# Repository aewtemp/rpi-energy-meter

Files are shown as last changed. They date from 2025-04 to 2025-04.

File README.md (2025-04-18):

# ----- W.I.P -----
# Raspberry-Pi Energy Meter

This Project is a combination of custom Hardware and Software, that will allow you to monitor your unique power situation in real time.

This project is derived from and inspired by the resources located at https://github.com/David00/rpi-power-monitor and https://learn.openenergymonitor.org.

## What does it do?
This code accompanies DIY circuitry that supports monitoring of up to 3 Phases with 6 current transformers each. The individual readings are then used in calculations to provide real data on consumption and generation, including the following key metrics:
* Voltage of every pahse
* Current on up to 6 channels per phase
* Power Factor
* Harmonics inspection through a built in snapshot/plotting mechanism.

The code takes thousands of samples per second, corrects for phase errors in the measurements, calculates the instantaneous power for the tens of thousands of sampled points, and uses the instantaneous power calculations to determine real power, apparent power, and power factor. This means the project is able to monitor any type of load, including reactive, capacitive, and resisitve loads.

## Where can I get it?
The whole Project is open sourced. You can order your PCBs via the Files provided in the [PCB Folder](PCB).  
You'll also find a [README](PCB/README.md) there which will provide more useful information.

## Installation & Documentation

### Ordering
#### Components for the PCB
Please take the respective components and their needed quantities from the [CSV](PCB/Production/RPiWattMeterHatv3.csv) inside the [PCB](PCB) folder.
#### The PCB
Just send the gerber files to the PCB Manufacturer of your choice.
If you provide the components file and the locations with the gerber files, you might be able to get the PCB nearly fully assembled.

### Preparing the Pi
#### System-Setup
You'll need a raspberry pi 3B with an installed operating system on it.
This has to be a 32-bit version, because the overlay file needed for the SPI-bus configuration won't work on 64-bit operating systems.
Currently supported operating systems are Debian (>11) and Ubuntu (>20.04)

* Copy the [overlay file (system_overlay/spi0-3cs-overlay.dtbo)](sytem_overlay/spi0-3cs-overlay.dtbo) into /boot/overlays  
* reboot

#### Installing the necessary software

### Installation and Configuration
#### Installation into the Cabinet
You will need 4 additional components to get the rpi-energy-meter up and running.
1. A DIN rail mountable power supply  
I had chosen this one: [MeanWell HDR-15-5](https://meanwell-ps.com/products/hdr-15-5)
2. 3 x fuse blocks, rated for 250V  
I had chosen this one: [XCELL UK5](https://www.uxcell.com/din-rail-mount-fuse-holder-terminal-blocks-screw-type-black-uk5-pack-p-1946790.html)
3. 3 x glass fuse, rated for 250V and 250mA  
I had chosen this one: [FUSE GLASS](https://www.digikey.de/en/products/detail/bel-fuse-inc/5HT-250-R/4439452)
4. Wires  
Ideally one would use black for the 230V live wires from and to the fuse holders, blue ones for the neutrals and red/black wires for the current transformer wires.  
The cross sections of the wires is:
    1. 230V/Neutal
        1. To the fuse blocks = 1.5mm² (15 AWG)
        1. From the fuse blocks = 0.5mm² (20 AWG)
        1. From the board (Neutral) = 0.5mm² (20 AWG)
    2. Current transformers
        1. Should be 0.5mm² or less (>= 20 AWG)

Select where you want your Voltage to be taken of for measurement. You'll have to select 3 sources, one for each phase.  
Connect wires from these points up to the fuse holders. From there you'll connect wires to the PCB - right where the imprint "DANGER HIGH VOLTAGE" is located.  
With the socket located at the bottom, left is phase 1, middle two are phase 2 and the right ones are phase 3.  
The Sequence is **N-L1-N-L2-N-L3**

#### Measuring required references
This step consists of some measurements which have to be taken in the cabinet and on the PCB. On the PCB are therefore some exposed through holes where you can take measurements from.

**!! BE CAREFUL WHEN TAKING MEASUREMENTS ON LIVE COMPONENTS !!**  

The following measurements have to be done:
* Voltages DC
    * 3.3V reference -> Exposed pads right next to the MCP3008 chips  
    Write down that value, it's needed later for the config.toml
    * Bias_V -> Exposed pads right above the Transformers on the PCB  
    Should be half of the reference Voltage
* Voltage AC
    * L{1,2,3}TRANS -> Exposed pads right next to the MCP3008 chips  
    Should read something from 2.0V to 2.2V RMS

#### Configuring the Energy-Meter

### Setting up a systemd service
* copy the [example systemd service file](examples/systemd/rpi-energy-meter.service) to /etc/systemd/system  
* modify the contents of /etc/systemd/systemd/rpi-energy-meter.service corresponding to your setup  
Most often you will need to adjust paths accordingly

### Expected results
#### Debug mode
The html charts generated by debug mode should look something like this  
[Phase 1](examples/debug/Phase_1.html?raw=true)  
[Phase 2](examples/debug/Phase_2.html?raw=true)  
[Phase 3](examples/debug/Phase_3.html?raw=true)

## Contributing

## Credits

---

## If you like what I did, you are welcome to leave me some support




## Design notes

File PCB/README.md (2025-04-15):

# ----- W.I.P -----
# Raspberry-Pi Energy Meter HAT
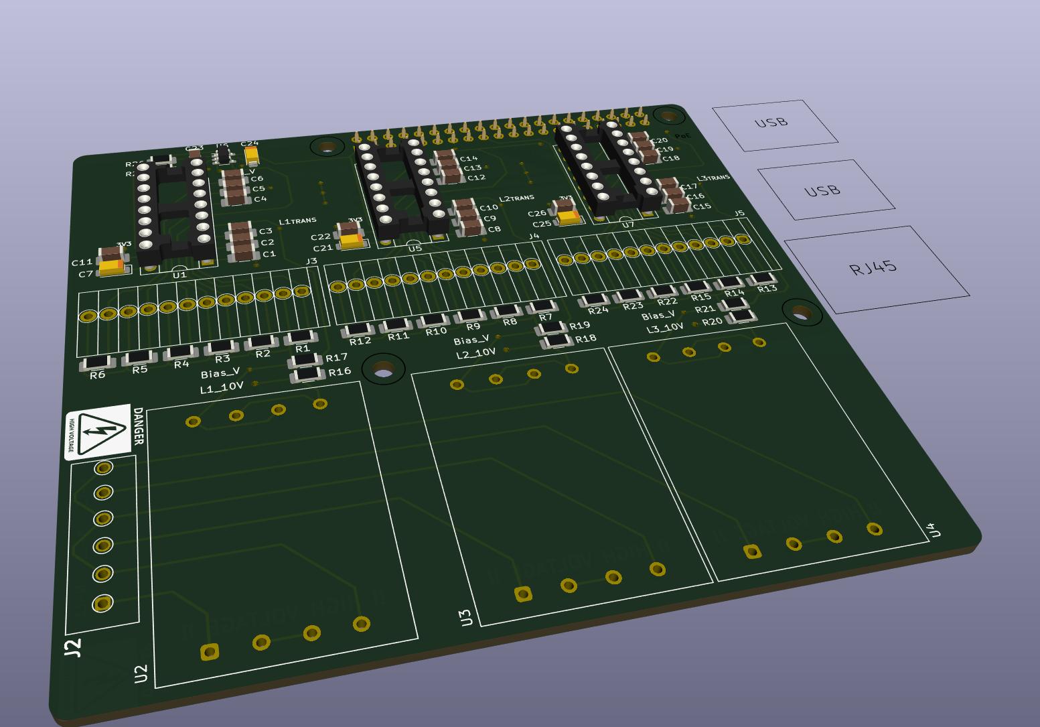
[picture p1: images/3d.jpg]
3D Image


## What does it do?
This PCB is designed for measuring electrical current across three phases, with 6 individual channels per phase. Each channel represents a separate current path and uses current transformers (CTs) for sensing. The board uses 22 Ohm burden resistors for each CT channel.

Additionally, the board incorporates transformers to step down the mains voltage to a measurable level for voltage monitoring. **Caution:** This board operates with potentially dangerous voltages. There is **no touch protection**, and **improper handling may result in electric shock**.

This is a DIY project and comes with **no warranty or guarantee** of safety or performance. Use at your own risk.  
I personally have this setup running now for 2 years.

## Pictures of running setup
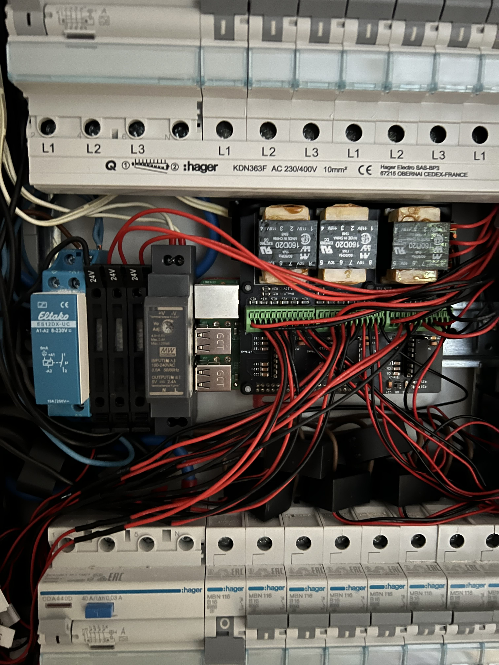
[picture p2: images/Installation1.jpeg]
Installation 1
  
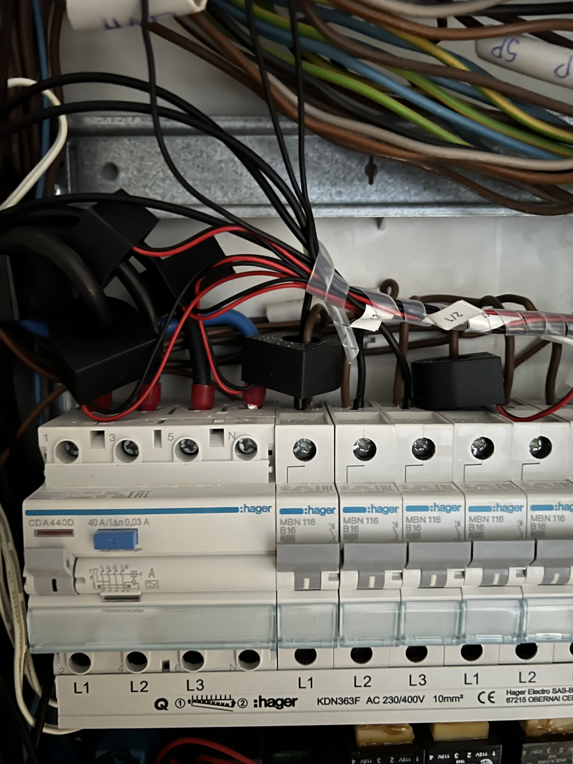
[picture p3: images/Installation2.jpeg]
Installation 2
  
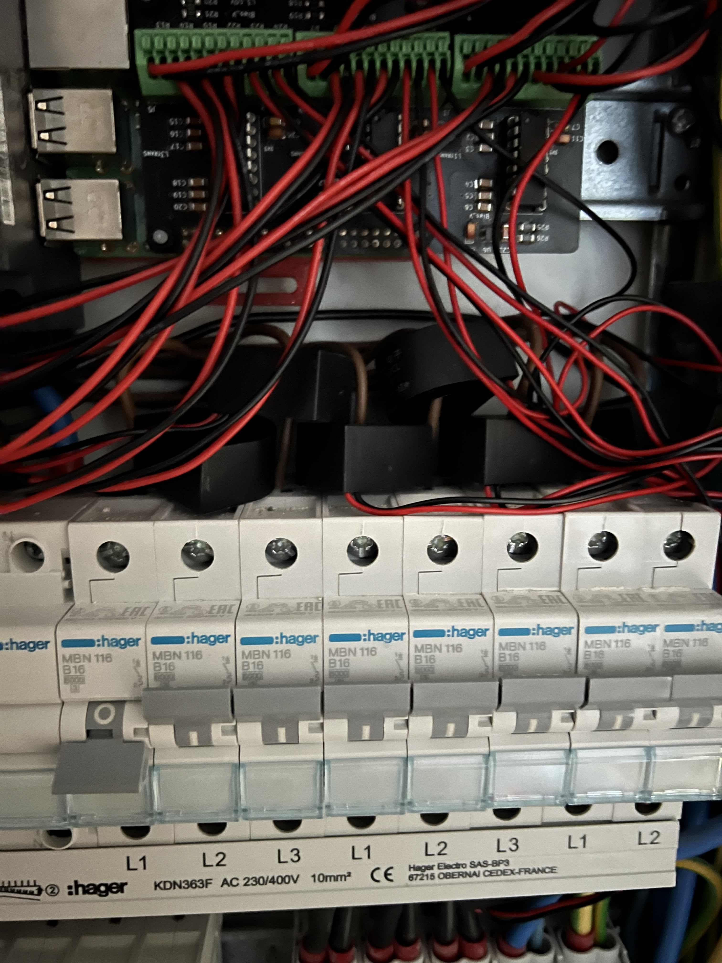
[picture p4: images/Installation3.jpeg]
Installation 3


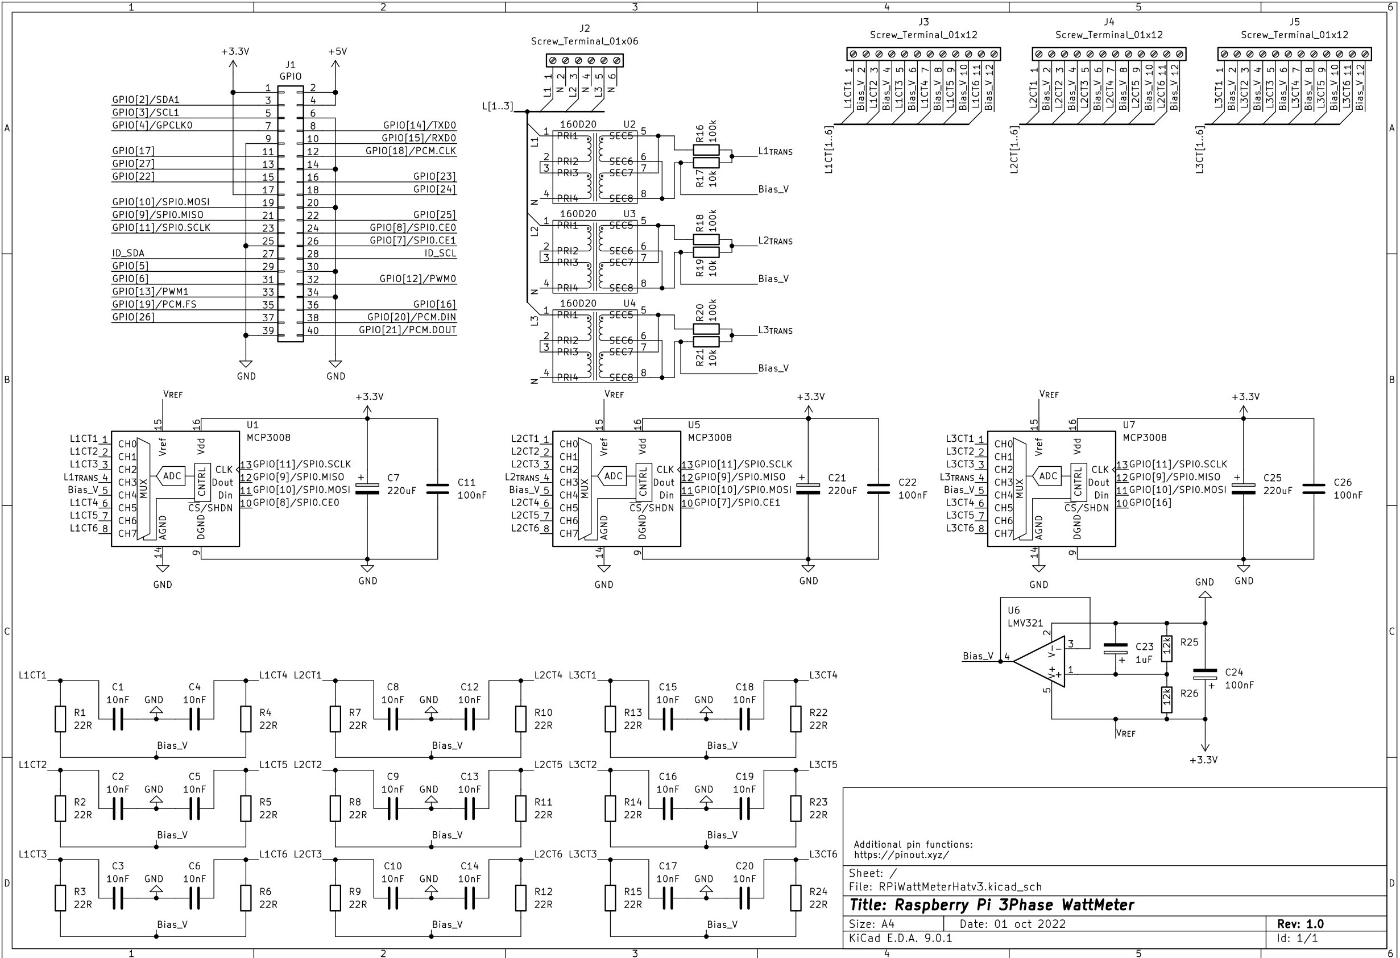
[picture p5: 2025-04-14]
images/schematics.jpg

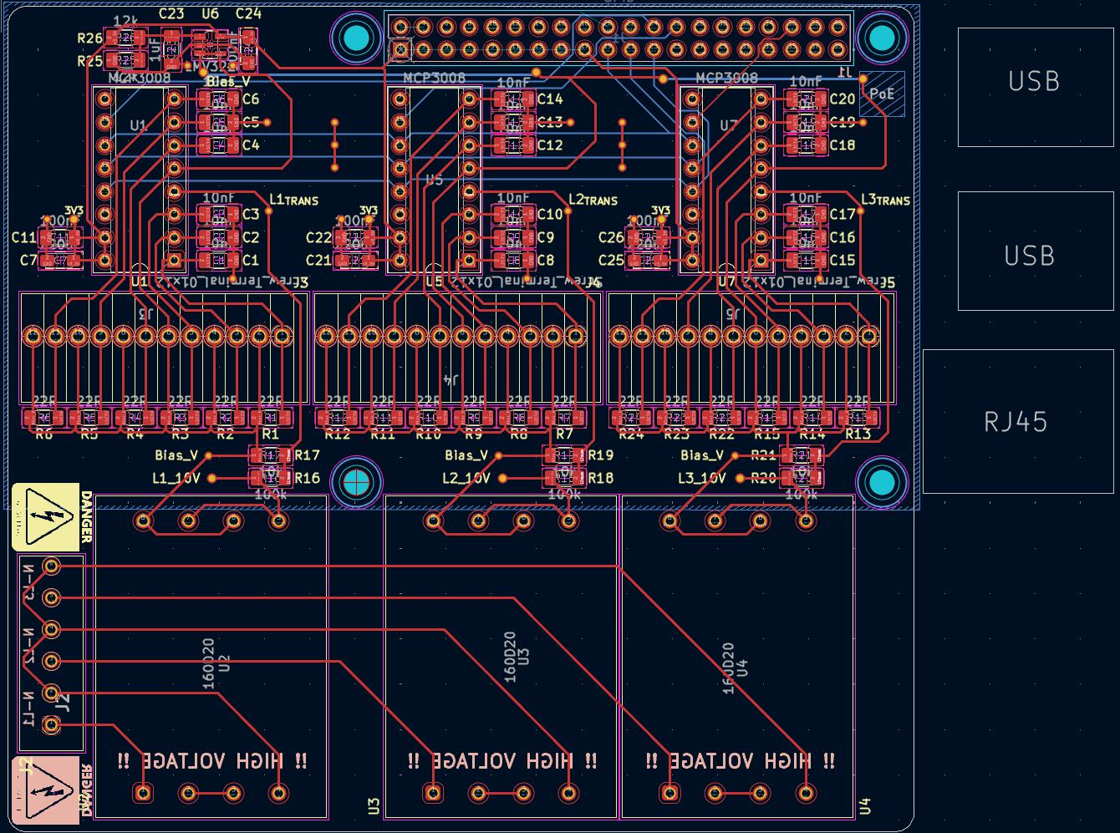
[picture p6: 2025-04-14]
images/layout.jpg

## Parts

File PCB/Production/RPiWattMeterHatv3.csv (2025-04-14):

Reference | Value | Footprint | Datasheet | Qty | DNP | Exclude from BOM | Exclude from Board
C1,C2,C3,C4,C5,C6,C8,C9,C10,C12,C13,C14,C15,C16,C17,C18,C19,C20 | 10nF | Capacitor_SMD:C_1206_3216Metric_Pad1.33x1.80mm_HandSolder | ~ | 18
C7,C21,C25 | 220uF | Capacitor_Tantalum_SMD:CP_EIA-3216-12_Kemet-S_Pad1.58x1.35mm_HandSolder | ~ | 3
C11,C22,C26 | 100nF | Capacitor_SMD:C_1206_3216Metric_Pad1.33x1.80mm_HandSolder | ~ | 3
C23 | 1uF | Capacitor_SMD:C_1206_3216Metric_Pad1.33x1.80mm_HandSolder | ~ | 1
C24 | 100nF | Capacitor_Tantalum_SMD:CP_EIA-3216-12_Kemet-S_Pad1.58x1.35mm_HandSolder | ~ | 1
J1 | GPIO | Connector_PinSocket_2.54mm:PinSocket_2x20_P2.54mm_Vertical | ~ | 1
J2 | Screw_Terminal_01x06 | RPiWattMeterFootprints:PhoenixContact_1891108 | ~ | 1
J3,J4,J5 | Screw_Terminal_01x12 | RPiWattMeterFootprints:PhoenixContact_PTSA 0,5_12-2,5-F | ~ | 3
R1,R2,R3,R4,R5,R6,R7,R8,R9,R10,R11,R12,R13,R14,R15,R22,R23,R24 | 22R | Resistor_SMD:R_1206_3216Metric_Pad1.30x1.75mm_HandSolder | ~ | 18
R16,R18,R20 | 100k | Resistor_SMD:R_1206_3216Metric_Pad1.30x1.75mm_HandSolder | ~ | 3
R17,R19,R21 | 10k | Resistor_SMD:R_1206_3216Metric_Pad1.30x1.75mm_HandSolder | ~ | 3
R25,R26 | 12k | Resistor_SMD:R_1206_3216Metric_Pad1.30x1.75mm_HandSolder | ~ | 2
U1,U5,U7 | MCP3008 | Package_DIP:DIP-16_W7.62mm_Socket | http://ww1.microchip.com/downloads/en/DeviceDoc/21295d.pdf | 3
U2,U3,U4 | 160D20 | RPiWattMeterFootprints:Hammond_160D20 |  | 3
U6 | LMV321 | Package_TO_SOT_SMD:SOT-23-5 | http://www.ti.com/lit/ds/symlink/lmv324.pdf | 1

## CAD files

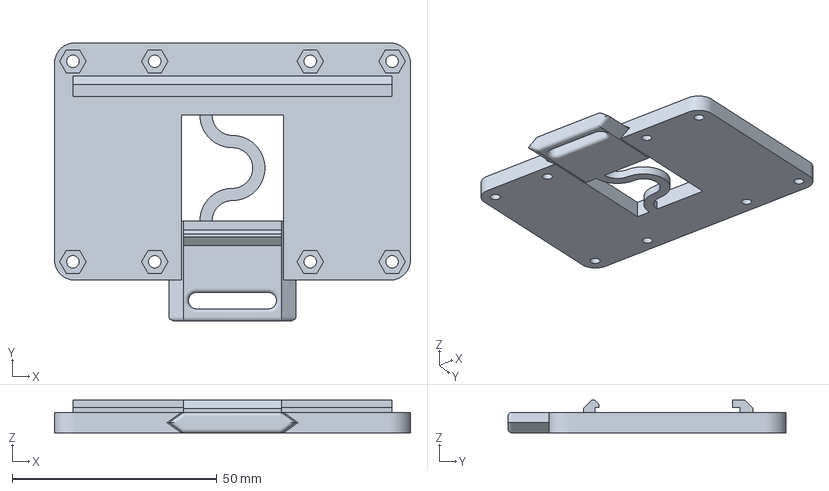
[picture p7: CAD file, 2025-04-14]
Printables/DIN Rail mount.3mf
87.0 x 68.0 x 8.00 mm

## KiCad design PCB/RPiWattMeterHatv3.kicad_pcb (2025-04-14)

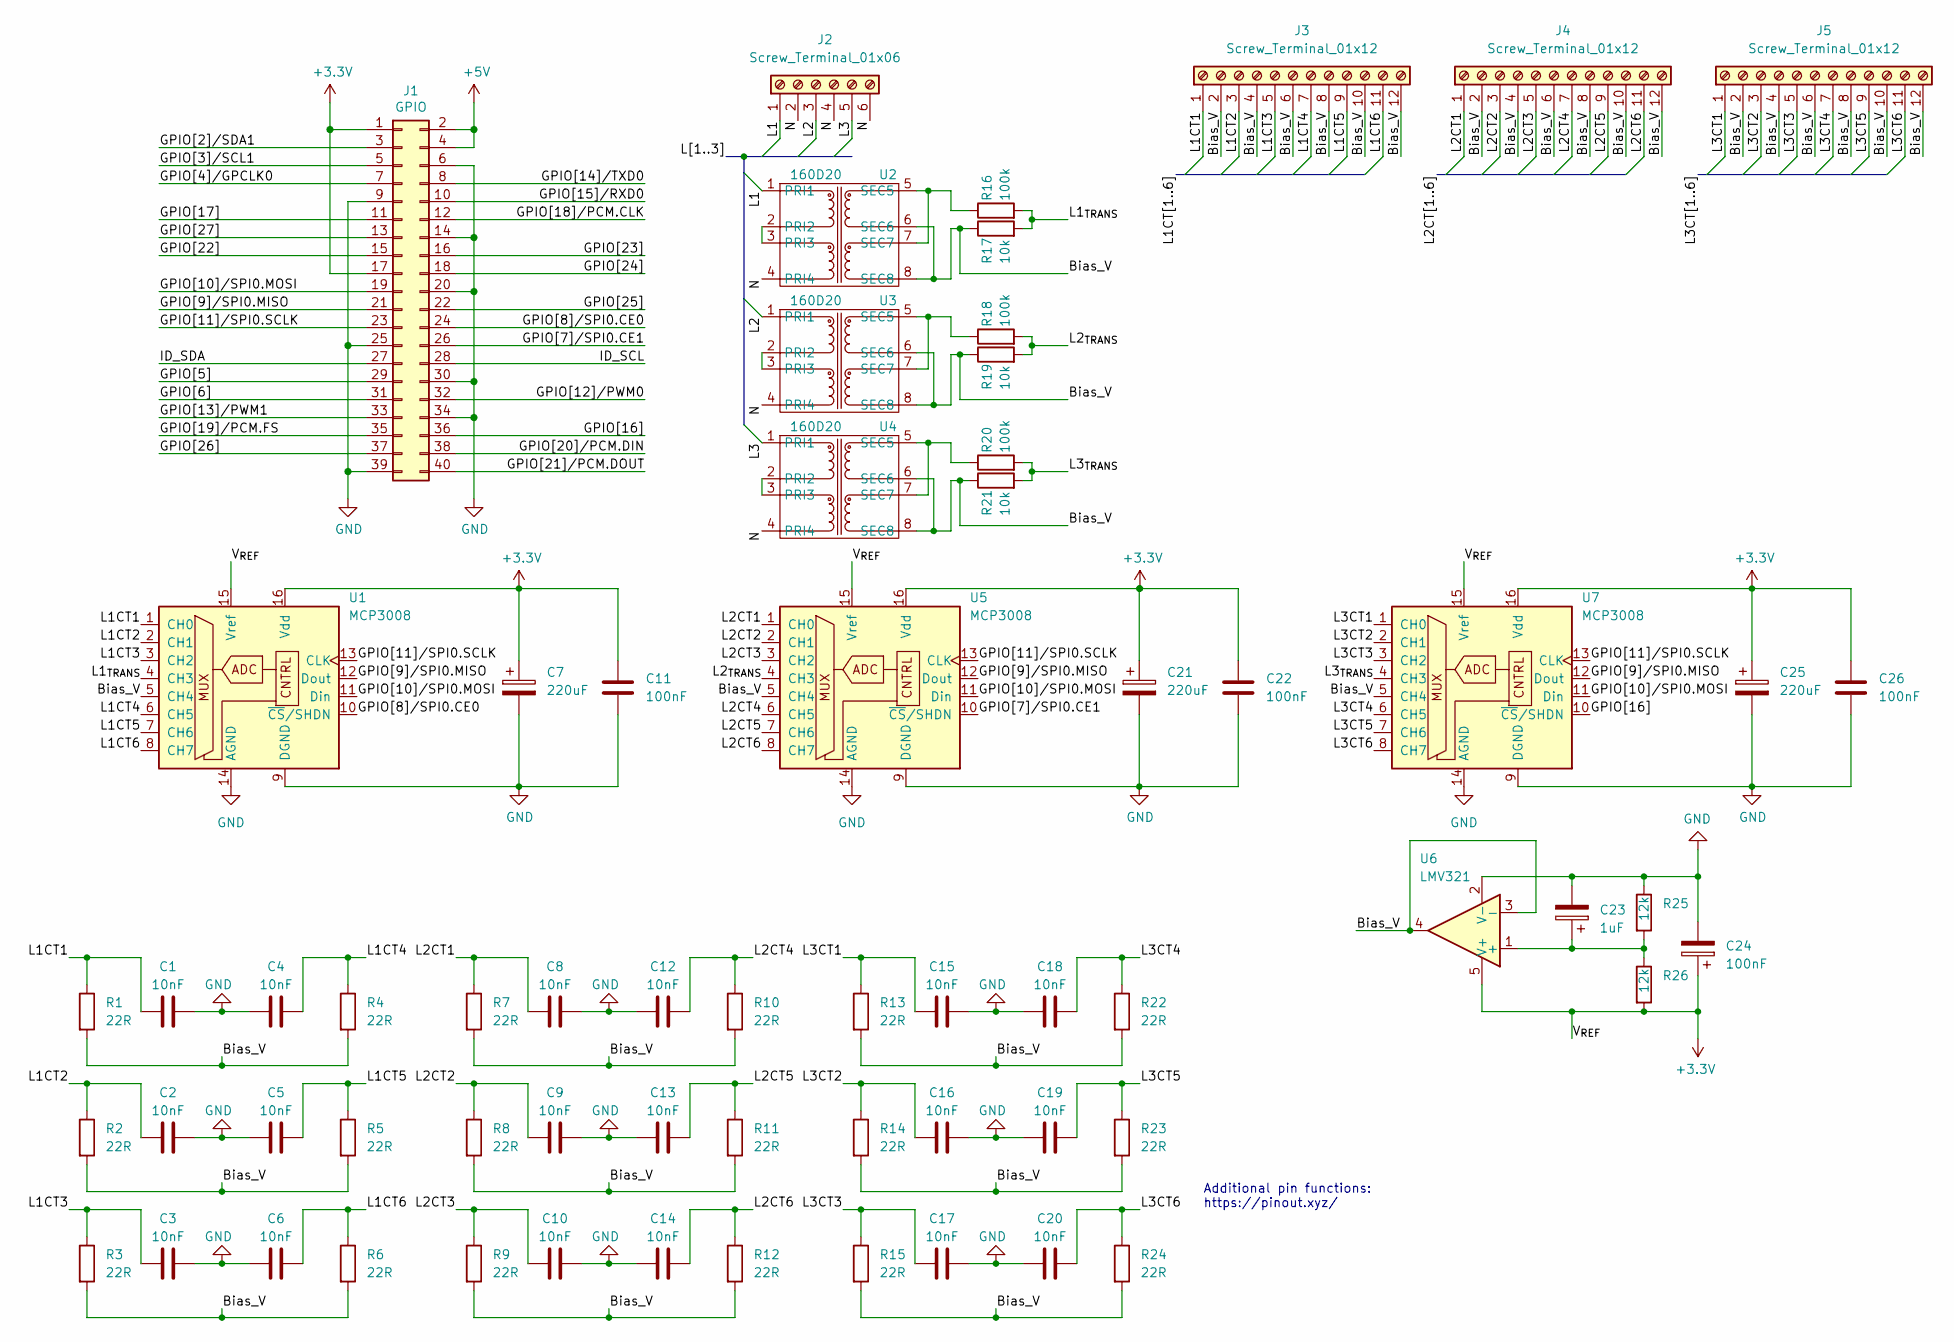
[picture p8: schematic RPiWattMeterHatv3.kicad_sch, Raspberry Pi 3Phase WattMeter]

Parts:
C1, C2, C3, C4, C5, C6, C8, C9, C10, C12, C13, C14, C15, C16, C17, C18, C19, C20: 10nF; C_1206_3216Metric_Pad1.33x1.80mm_HandSolder
C7, C21, C25: 220uF; CP_EIA-3216-12_Kemet-S_Pad1.58x1.35mm_HandSolder
C11, C22, C26: 100nF; C_1206_3216Metric_Pad1.33x1.80mm_HandSolder
C23: 1uF; C_1206_3216Metric_Pad1.33x1.80mm_HandSolder
C24: 100nF; CP_EIA-3216-12_Kemet-S_Pad1.58x1.35mm_HandSolder
J1: GPIO; PinSocket_2x20_P2.54mm_Vertical
J2: Screw_Terminal_01x06; PhoenixContact_1891108
J3, J4, J5: Screw_Terminal_01x12; PhoenixContact_PTSA 0,5_12-2,5-F
R1, R2, R3, R4, R5, R6, R7, R8, R9, R10, R11, R12, R13, R14, R15, R22, R23, R24: 22R; R_1206_3216Metric_Pad1.30x1.75mm_HandSolder
R16, R18, R20: 100k; R_1206_3216Metric_Pad1.30x1.75mm_HandSolder
R17, R19, R21: 10k; R_1206_3216Metric_Pad1.30x1.75mm_HandSolder
R25, R26: 12k; R_1206_3216Metric_Pad1.30x1.75mm_HandSolder
U1, U5, U7: MCP3008; DIP-16_W7.62mm_Socket
U2, U3, U4: 160D20; Hammond_160D20
U6: LMV321; SOT-23-5

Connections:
+3.3V: C7.1, C11.1, C21.1, C22.1, C24.1, C25.1, C26.1, J1.1, J1.17, R26.2, U1.15 (Vref), U1.16 (Vdd), U5.15 (Vref), U5.16 (Vdd), U6.5 (V+), U7.15 (Vref), U7.16 (Vdd)
+5V: J1.2, J1.4
/Bias_V: J3.2, J3.4, J3.6, J3.8, J3.10, J3.12, J4.2, J4.4, J4.6, J4.8, J4.10, J4.12, J5.2, J5.4, J5.6, J5.8, J5.10, J5.12, R1.2, R2.2, R3.2, R4.2, R5.2, R6.2, R7.2, R8.2, R9.2, R10.2, R11.2, R12.2, R13.2, R14.2, R15.2, R17.1, R19.1, R21.1, R22.2, R23.2, R24.2, U1.5 (CH4), U2.6 (SEC6), U2.8 (SEC8), U3.6 (SEC6), U3.8 (SEC8), U4.6 (SEC6), U4.8 (SEC8), U5.5 (CH4), U6.3 (-), U6.4, U7.5 (CH4)
/GPIO[2]/SDA1: J1.3
/GPIO[3]/SCL1: J1.5
/GPIO[4]/GPCLK0: J1.7
/GPIO[5]: J1.29
/GPIO[6]: J1.31
/GPIO[7]/SPI0.CE1: J1.26, U5.10 (~CS/SHDN)
/GPIO[8]/SPI0.CE0: J1.24, U1.10 (~CS/SHDN)
/GPIO[9]/SPI0.MISO: J1.21, U1.12 (Dout), U5.12 (Dout), U7.12 (Dout)
/GPIO[10]/SPI0.MOSI: J1.19, U1.11 (Din), U5.11 (Din), U7.11 (Din)
/GPIO[11]/SPI0.SCLK: J1.23, U1.13 (CLK), U5.13 (CLK), U7.13 (CLK)
/GPIO[12]/PWM0: J1.32
/GPIO[13]/PWM1: J1.33
/GPIO[14]/TXD0: J1.8
/GPIO[15]/RXD0: J1.10
/GPIO[16]: J1.36, U7.10 (~CS/SHDN)
/GPIO[17]: J1.11
/GPIO[18]/PCM.CLK: J1.12
/GPIO[19]/PCM.FS: J1.35
/GPIO[20]/PCM.DIN: J1.38
/GPIO[21]/PCM.DOUT: J1.40
/GPIO[22]: J1.15
/GPIO[23]: J1.16
/GPIO[24]: J1.18
/GPIO[25]: J1.22
/GPIO[26]: J1.37
/GPIO[27]: J1.13
/ID_SCL: J1.28
/ID_SDA: J1.27
/L1: J2.1, U2.1 (PRI1)
/L1CT1: C1.2, J3.1, R1.1, U1.1 (CH0)
/L1CT2: C2.2, J3.3, R2.1, U1.2 (CH1)
/L1CT3: C3.2, J3.5, R3.1, U1.3 (CH2)
/L1CT4: C4.1, J3.7, R4.1, U1.6 (CH5)
/L1CT5: C5.1, J3.9, R5.1, U1.7 (CH6)
/L1CT6: C6.1, J3.11, R6.1, U1.8 (CH7)
/L1_{TRANS}: R16.2, R17.2, U1.4 (CH3)
/L2: J2.3, U3.1 (PRI1)
/L2CT1: C8.2, J4.1, R7.1, U5.1 (CH0)
/L2CT2: C9.2, J4.3, R8.1, U5.2 (CH1)
/L2CT3: C10.2, J4.5, R9.1, U5.3 (CH2)
/L2CT4: C12.1, J4.7, R10.1, U5.6 (CH5)
/L2CT5: C13.1, J4.9, R11.1, U5.7 (CH6)
/L2CT6: C14.1, J4.11, R12.1, U5.8 (CH7)
/L2_{TRANS}: R18.2, R19.2, U5.4 (CH3)
/L3: J2.5, U4.1 (PRI1)
/L3CT1: C15.2, J5.1, R13.1, U7.1 (CH0)
/L3CT2: C16.2, J5.3, R14.1, U7.2 (CH1)
/L3CT3: C17.2, J5.5, R15.1, U7.3 (CH2)
/L3CT4: C18.1, J5.7, R22.1, U7.6 (CH5)
/L3CT5: C19.1, J5.9, R23.1, U7.7 (CH6)
/L3CT6: C20.1, J5.11, R24.1, U7.8 (CH7)
/L3_{TRANS}: R20.2, R21.2, U7.4 (CH3)
/N: J2.2, J2.4, J2.6, U2.4 (PRI4), U3.4 (PRI4), U4.4 (PRI4)
GND: C1.1, C2.1, C3.1, C4.2, C5.2, C6.2, C7.2, C8.1, C9.1, C10.1, C11.2, C12.2, C13.2, C14.2, C15.1, C16.1, C17.1, C18.2, C19.2, C20.2, C21.2, C22.2, C23.2, C24.2, C25.2, C26.2, J1.6, J1.9, J1.14, J1.20, J1.25, J1.30, J1.34, J1.39, R25.1, U1.9 (DGND), U1.14 (AGND), U5.9 (DGND), U5.14 (AGND), U6.2 (V-), U7.9 (DGND), U7.14 (AGND)
unnamed: C23.1, R25.2, R26.1, U6.1 (+)
unnamed: R16.1, U2.5 (SEC5), U2.7 (SEC7)
unnamed: R18.1, U3.5 (SEC5), U3.7 (SEC7)
unnamed: R20.1, U4.5 (SEC5), U4.7 (SEC7)
unnamed: U2.2 (PRI2), U2.3 (PRI3)
unnamed: U3.2 (PRI2), U3.3 (PRI3)
unnamed: U4.2 (PRI2), U4.3 (PRI3)

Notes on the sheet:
Additional pin functions: https://pinout.xyz/

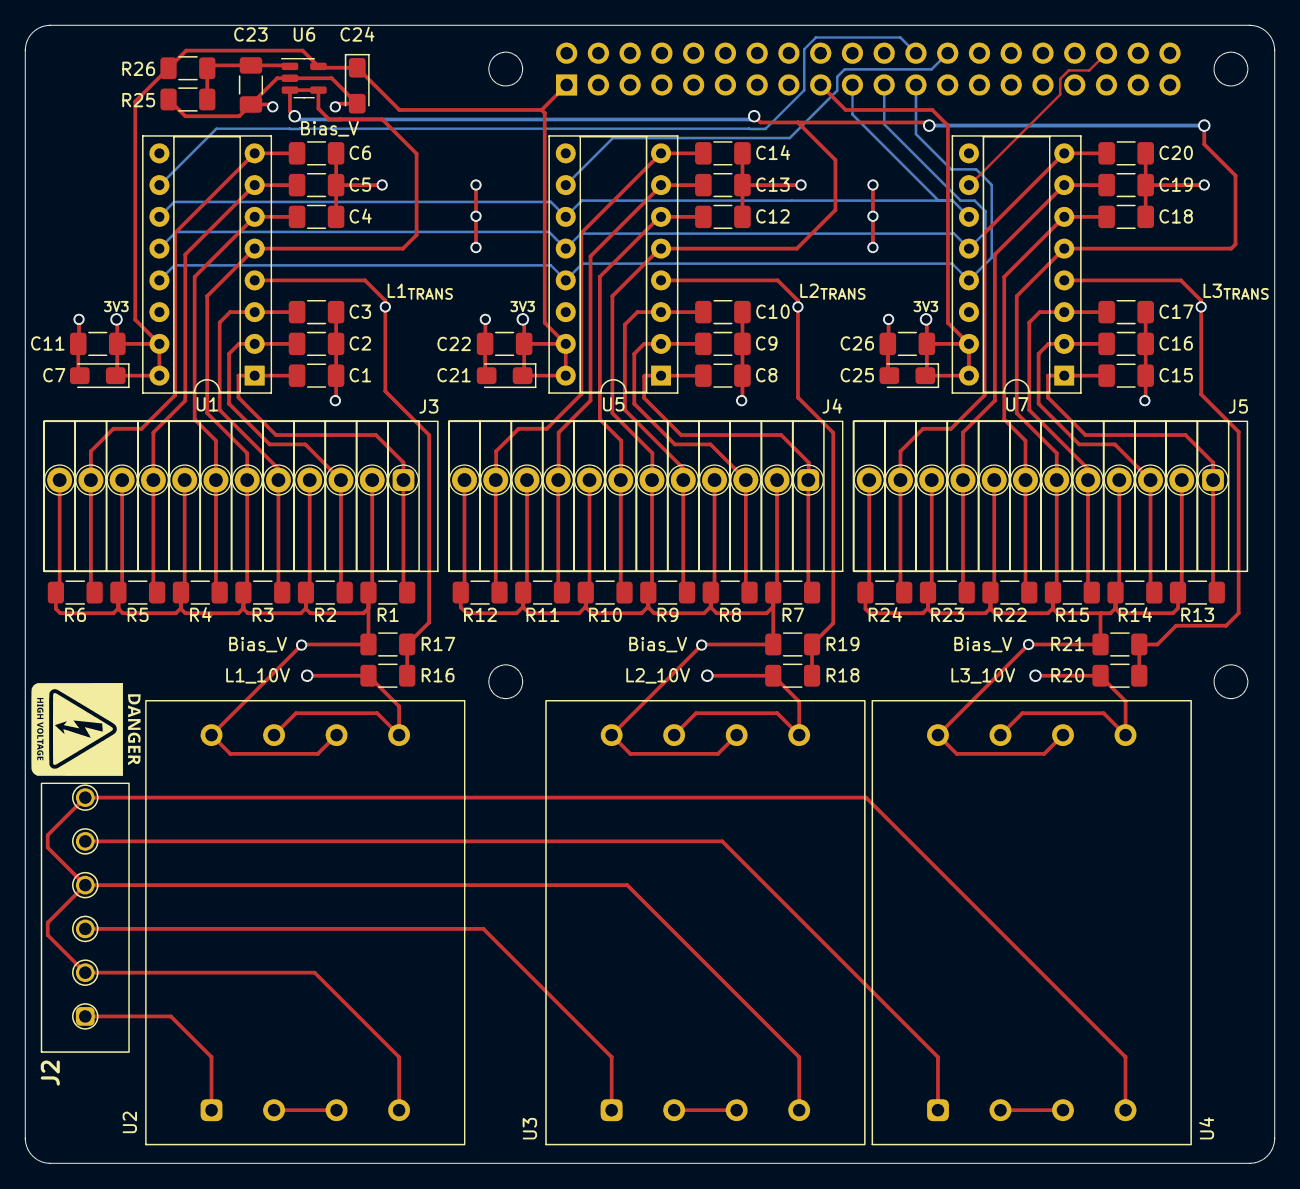
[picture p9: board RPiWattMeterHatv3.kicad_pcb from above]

Board: 2 copper layers, 99.9 x 91.0 mm, 68 parts (1 on the bottom side), 42 nets.

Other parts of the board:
MH1, MH2, MH3, MH4: MountingHole_2.7mm_M2.5

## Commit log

2025-04-14 Pushed PCB data, some images and updated READMEs.
    [RPiWattMeterHatv3-B_Cu.gbl, RPiWattMeterHatv3-B_Mask.gbs, RPiWattMeterHatv3-B_Paste.gbp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]
2025-04-16 fixes and updates to logging, configuration and samples
2025-04-18 removed KiCad Backups
2026-03-24 fix bugs and improve performance across all core modules
    Bug fixes:
    - samples.py: _energy init used totals[0] for all 6 CTs instead of totals[i], causing all CTs to share CT1's kWh on restart
    - utils.py: generate_data overwrote the time vector t with zeros before using it for sine generation, producing flat-line test data
    - utils.py: VAC scaling factor hardcoded to PHASES["1"] for all phases; phases 2+3 got wrong voltage scaling
    - mcp3008.py: operator precedence bug (8 + channel << 4) selected wrong SPI channel for channels 1-7
    - energy_meter.py: calibration mode used stale loop variable i instead of phase_selection
    - energy_meter.py: averages[2] hardcoded 3 phases, crashes with IndexError i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
2026-03-24 Migrate to Ruff, fix critical bugs, and remove dead code
    Linting/formatting:
    - Replace black + isort + pylint with Ruff in pyproject.toml
    - Bump requires-python to >=3.9 (3.8 is EOL)
    - Update __main__.py tests command to use ruff check/format
    - Apply ruff auto-formatting across all source files
    Critical bug fixes:
    - Fix missing `from copy import copy` — calibration mode crashed with NameError
    - Fix hardcoded write_config("config.toml") — now uses self.config_path from CLI arg
    - Implement atomic config writes (tempfile + os.replace) to prevent kWh corruption
    Architecture improvements:
    - Replace wildcard imports in energy_meter.py with explicit imports
    - Defer plotly import inside plot_d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
